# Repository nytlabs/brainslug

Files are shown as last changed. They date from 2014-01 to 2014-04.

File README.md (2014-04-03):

brainslug
=========

Brainslug is the internal name for a wearable we're experimenting with - this is the board that powers it. It combines an RFduino (ARM Cortex + BLE stack) and some MOSFET drivers to actuate high-current peripherals (heat pad, super-bright LED, peltier junction, etc).

Eagle board files for a small RFD22301 shield

This board allows an RFD22301 unit to address a dual-channel N-MOSFET IC on pins 0 and 1.

BOM:

(1) MOSFET IC http://www.digikey.com/product-detail/en/FDS6911/FDS6911CT-ND/1197695

(1) 3V3 regulator https://www.sparkfun.com/products/11253

(1) RFD22301 http://www.semiconductorstore.com/cart/pc/viewPrd.asp?idproduct=48872

(1) 10uF 0805 cap https://www.sparkfun.com/products/11244 (not strictly necessary, but wise)

...the board is laid out to use SMD JST connectors (https://www.sparkfun.com/products/8612) for battery and two loads, but you can also solder your own connectiors

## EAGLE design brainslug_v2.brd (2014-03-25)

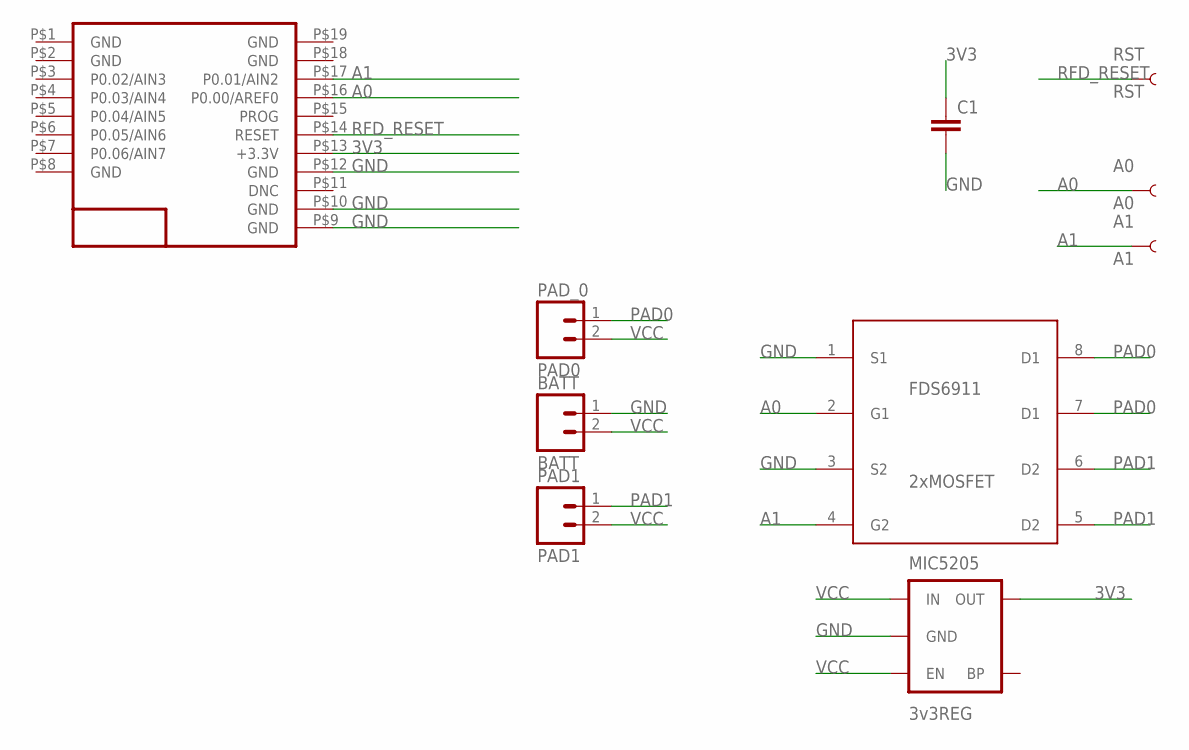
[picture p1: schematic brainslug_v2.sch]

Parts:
A0: A0; PAD.03X.03
A1: A1; PAD.03X.03
BATT: BATT; JST-2-SMD
C1: CAP; C3216
FDS6911: 2xMOSFET; SO8
MIC5205: 3v3REG; SOT23-5
PAD1: PAD1; JST-2-SMD
PAD_0: PAD0; JST-2-SMD
RST: RST; PAD.03X.03
U$1: RFD22301; RFD21733

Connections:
3V3: C1.1, MIC5205.5 (OUT), U$1.P$13 (+3.3V)
A0: A0.P$1, FDS6911.2 (G1), U$1.P$16 (P0.00/AREF0)
A1: A1.P$1, FDS6911.4 (G2), U$1.P$17 (P0.01/AIN2)
GND: BATT.1 (2), C1.2, FDS6911.1 (S1), FDS6911.3 (S2), MIC5205.2 (GND), U$1.P$9 (GND), U$1.P$10 (GND), U$1.P$12 (GND)
PAD0: FDS6911.7 (D1), FDS6911.8 (D1), PAD_0.1 (2)
PAD1: FDS6911.5 (D2), FDS6911.6 (D2), PAD1.1 (2)
RFD_RESET: RST.P$1, U$1.P$14 (RESET)
VCC: BATT.2 (1), MIC5205.1 (IN), MIC5205.3 (EN), PAD1.2 (1), PAD_0.2 (1)

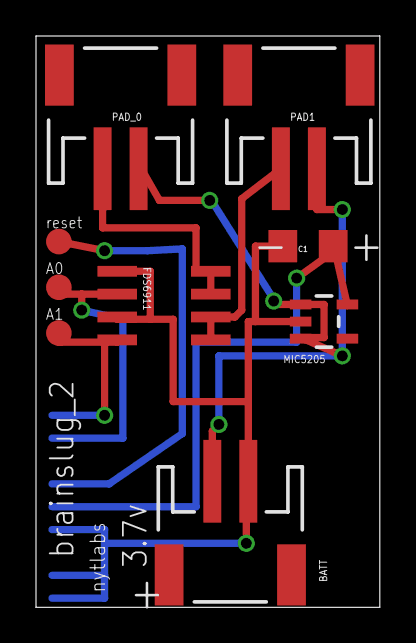
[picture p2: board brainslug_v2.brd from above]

Board: 2 copper layers, 19.1 x 31.7 mm, 10 parts (1 on the bottom side), 8 nets.

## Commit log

2014-01-17 cleaning up unusable first iterations of board - v5 is the first stable version
    [brainslug_2.brd, brainslug_2.sch, brainslug_34drc.brd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]
2014-03-25 added more robust programming header, some other small improvements
    [brainslug_v2.brd, brainslug_v2.sch]

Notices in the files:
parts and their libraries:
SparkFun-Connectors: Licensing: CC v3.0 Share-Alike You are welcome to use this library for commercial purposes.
